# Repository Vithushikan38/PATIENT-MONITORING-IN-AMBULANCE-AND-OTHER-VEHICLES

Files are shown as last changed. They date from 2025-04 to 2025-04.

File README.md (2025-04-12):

# VITAL_SYNC  - Patient monitoring in ambulances and other vehicles



Team

- 2021/E/074    K. Vashiharan -https://www.linkedin.com/in/vashiharan02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      
- 2021/E/164    T. Sarujan    -https://www.linkedin.com/in/sarujan-thirunavukkarasu-2b72bb2b5lipi=urn%3Ali%3Apage%3Ad_flagship3_profile_view_base_contact_details%3Bo2gnX580QsemtR7ihnrzcw%3D%3D
- 2021/E/169    V. Vithushikan-https://www.linkedin.com/in/vvithushikan21
- 2021/E/189    R. Nidhushan  -https://www.linkedin.com/in/nidhushan-rajendran-a22a16244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

Introduction

In emergency situations, timely medical intervention is crucial to saving lives. However, during patient transportation, whether in ambulances or other vehicles, continuous health monitoring remains a significant challenge. Delays in detecting critical conditions can worsen health outcomes, and the lack of real-time communication between vehicles and hospitals further complicates emergency response efforts. Our project aims to develop an advanced patient monitoring system that ensures real-time tracking of vital signs during transportation, enhancing pre-hospital care and improving patient outcomes.

System Architecture


Circuit Design



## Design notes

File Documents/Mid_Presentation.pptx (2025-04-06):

## Project Title: Patient Monitoring in Ambulance and Other Vehicles Course: EC6020: Embedded Systems Design Group No: 31

Team Members:
- 2021/E/074 K. Vashiharan
- 2021/E/164 T. Sarujan
- 2021/E/169 V. Vithushikan
- 2021/E/189 R. Nidhushan

## Introduction

This project addresses the challenge of continuous health monitoring during patient transportation.
The lack of real-time communication with hospitals can worsen patient outcomes.
To improve emergency response, the proposed system enables real-time tracking of vital signs and location, ensuring timely medical intervention and better patient care.

## Problem Statement

Key Challenges:
➢ Delayed response due to lack of real-time data sharing, delaying hospital preparation.
➢ Manual reporting by paramedics can introduce errors
➢ Existing systems are mostly restricted to ambulances.

## Proposed Solution

- Real-time health monitoring (Heart rate, SpO₂, temperature, GPS tracking).
- Cloud-based data transmission for seamless hospital access.
- Instant alerts for critical conditions.
- Multi-vehicle compatibility (ambulances, police, rescue teams,personal vehicles).
- User-friendly dashboard for hospital and paramedics.

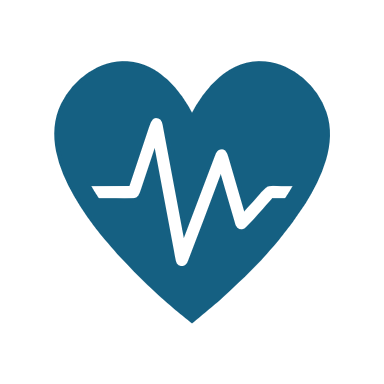
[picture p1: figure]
Heart with Pulse

## Novelty of the Project

- Multi-Vehicle Integration – Not limited to ambulances.
- Predictive Analytics – Alerts before deterioration.
- Low-Cost IoT Implementation – ESP32 + cloud services.
- Real-Time Communication – Mobile & web apps.
- Scalability – Expandable for multiple hospitals/vehicles.

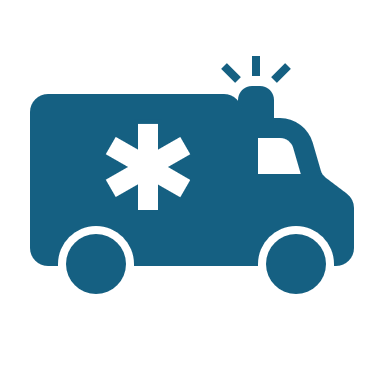
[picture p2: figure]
Ambulance

## High-Level Architecture

- ESP32 – Main controller.
- MAX30100 – Heart rate & SpO₂ sensor.
- DS18B20 – Temperature sensor.
- NEO-6M GPS – Location tracking.
- OLED Display – Onboard status monitoring.
- Cloud Integration – Data transmission.
- Mobile & Web Apps – Real-time patient data visualization.

## Circuit Design

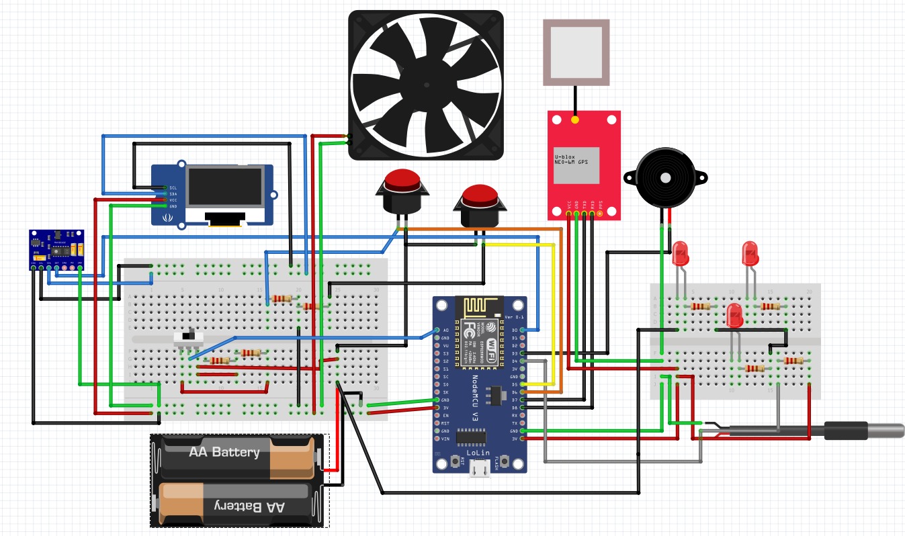
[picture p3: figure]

## WebApp

https://nidhushan13nds.github.io/PATIENT-MONITORING-IN-AMBULANCE-AND-OTHER-VEHICLES/

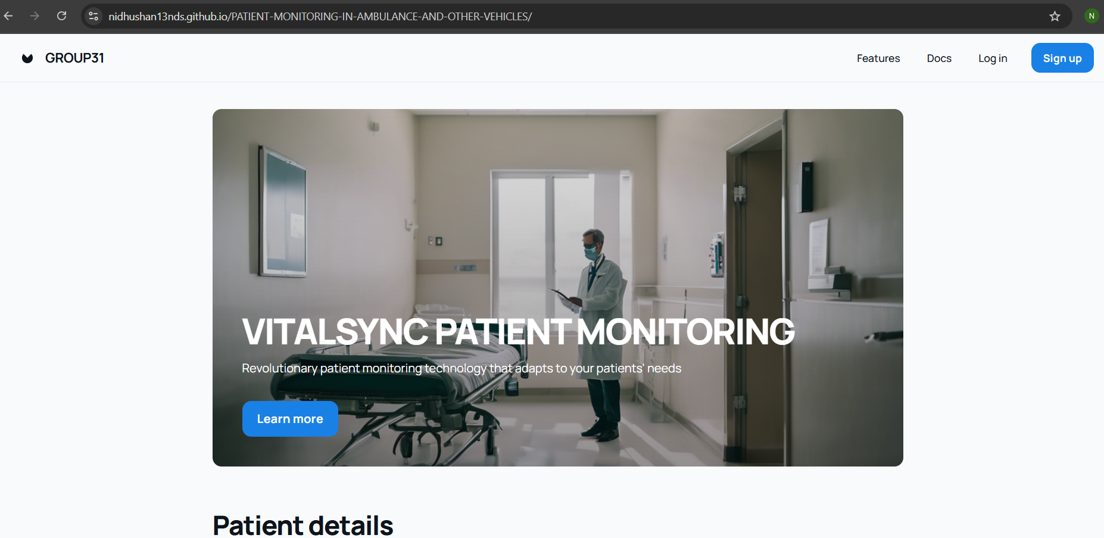
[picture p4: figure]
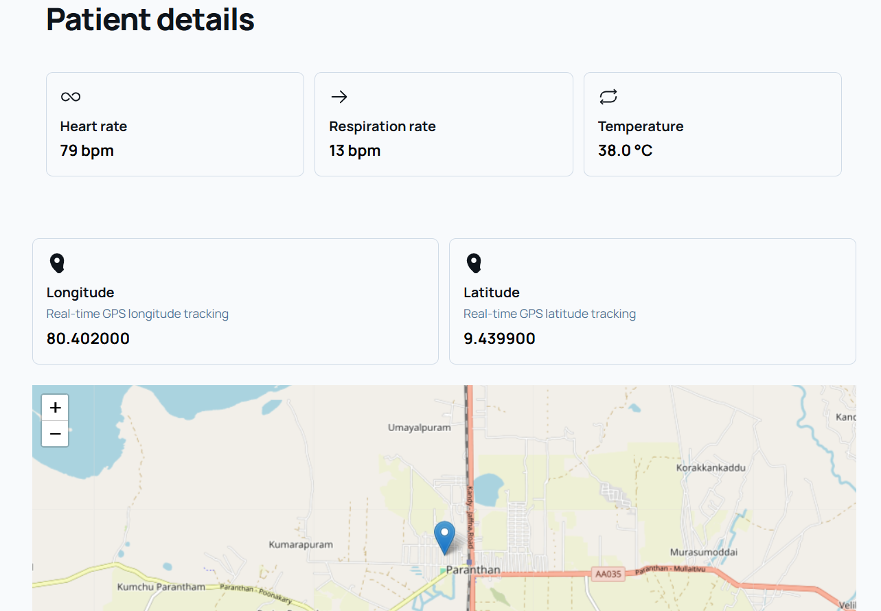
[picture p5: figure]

## Timeline

Activity | Weeks
| 5 | 6 | 7 | 8 | 9 | 10 | 11 | 12 | 13 | 14
Find and purchase components
Design the system and do initial testing
Assemble the hardware and write the firmware
Integrate the sensors and display
Build the web application and set up the database
Test the system and improve the user interface
Fix any issues and do final integration
Write the documentation and prepare for the presentation
Final review and project submission

## Budget

components | price
ESP32 | 1300
DS18B20 temperature sensor | 300
MAX30100 heart rate sensor | 500
NEO6MV2 gps module | 1500
OLED mini display 0.96 inch | 950
Copper board (5cm*7cm) | 150
Jumper wires(40pcs) | 300
Push button, Switch | 80
Outer cover & Other

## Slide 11

Thank you

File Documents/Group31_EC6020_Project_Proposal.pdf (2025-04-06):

GROUP NO - 31

MEMBERS

2021/E/074 K. Vashiharan

2021/E/164 T.Sarujan

2021/E/169 V.Vithushikan

2021/E/189 R.Nidhushan

## PROJECT PROPOSAL

## PATIENT MONITORING IN AMBULANCE AND OTHER VEHICLES

## EC6020:EMBEDDED SYSTEMS DESIGN

## Introduction

In emergency situations, timely medical intervention is crucial to saving lives. However, during patient transportation, whether in ambulances or other vehicles, continuous health monitoring remains a significant challenge. Delays in detecting critical conditions can worsen health outcomes, and the lack of real-time communication between vehicles and hospitals further complicates emergency response efforts. Our project aims to develop an advanced patient monitoring system that ensures real-time tracking of vital signs during transportation, enhancing pre-hospital care and improving patient outcomes.

## Problem Statement

Currently, there is no comprehensive system to monitor patients' real-time health parameters while they are being transported to hospitals. Some critical challenges include:

- Delayed Medical Response: Lack of real-time data sharing leads to delays in preparing hospital facilities for incoming patients.
- Inconsistent Data Transmission: Manual reporting by paramedics can introduce errors and delays.
- Limited Vehicle Integration: Existing systems are mostly restricted to ambulances, leaving other emergency vehicles without adequate monitoring solutions.
- Lack of Predictive Analytics: Current solutions lack the ability to predict potential health deteriorations during transport.

These issues lead to suboptimal emergency care, increased hospital burden, and in some cases, loss of life due to delayed treatment.

## Proposed Solution

To address these challenges, our system will provide a real-time, cloud-based patient monitoring solution that can be deployed in ambulances and other emergency vehicles. Key features include:

1. Real-time Health Monitoring:
- Sensors to continuously measure vital signs such as heart rate, oxygen saturation, temperature, and GPS location.
- Integration with wearable devices for seamless patient data acquisition.
2. Cloud-Based Data Transmission:
- Secure transmission of patient health data to hospital systems via cloud infrastructure.
- Mobile and web applications for paramedics and hospital staff to track patient status.
3. Alerts:
- Instant alerts to medical staff in case of abnormalities.
4. Multi-Vehicle Compatibility:
- Designed for ambulances, police vehicles, rescue teams, and other emergency transport modes.
5. User-Friendly Interface:
- Interactive dashboards for monitoring via mobile and desktop applications.
- Two-way communication between paramedics and hospital teams.

## Novelty of the Project

Our proposed system offers several

novel features that differentiate it from existing solutions:

- Multi-Vehicle Integration: Unlike conventional ambulance-only solutions, our system supports deployment in various emergency vehicles, broadening its application.
- provide proactive alerts, improving patient safety during transport.
- Low-Cost IoT Solution: Utilizing affordable microcontrollers and cloud services to ensure cost-effective implementation.
- Seamless Communication: Integrated mobile and desktop applications will enable real-time interaction between hospital and transport teams.
- Scalability and Flexibility: The system can be scaled to accommodate multiple vehicles and hospital networks, ensuring adaptability across healthcare infrastructures.

## HIGH-LEVEL ARCHITECTURE

1. ESP32 Development Board
- The dual-core processor on the ESP32, together with Wi-Fi and Bluetooth, can comfortably support a load of several sensors that can send updates in real time to cloud platforms.
Low power consumption, and thus ideal for mobile use in ambulances.
Robust SDKs and libraries for integrating different types of communication protocols and peripherals.
- It will serve as the main controller to process and forward the sensor data to cloud servers for real-time access.
2. MAX30102 Pulse Oximeter and Heart Rate Sensor
- Accurate heart rate and SpO₂ measurement, essential for patients suffering from respiratory or cardiac disorders.

Compact size, low power consumption; hence, suitable for portable devices.

- Keeps monitoring the vital signs and transmits the data to ESP32 for further processing and radio transmission.
3. DS18B20 Digital Temperature Sensor
- A high-accuracy, easy-to-use digital temperature sensor.

Suitable for applications that need consistent monitoring of temperature.

- Measures the body temperature of the patient and feeds it to the system in real time.

4. NEO-6M GPS Module
- Reliable GPS module for accurate tracking of the ambulance.

Compact size, and compatible with ESP32.

- Tracks the location of the ambulance to estimate the time of arrival by the hospital staff and to prepare accordingly.
5. OLED Display
- Provides real-time feedback to the ambulance staff regarding the health status of the patient and functionality of the device, Lightweight and energy efficiency.
- Displays vital parameters such as heart rate, oxygen saturation, temperature, and connection status directly in the ambulance.
8. Mobile and Web Applications: Flutter Framework
- Cross-platform development assures consistent user experience across mobile and desktop devices. Intuitive UI for real-time monitoring by hospital staff.
- Displays the patient's health data and ambulance location to hospital staff for better preparation.
9. Power Supply and Battery Backup Reason for Selection: Ensures that the system operates without interruption, even when there is power fluctuation inside the ambulance. Role: Supplies constant power to sensors, ESP32, and display unit

CIRCUIT DESIGN

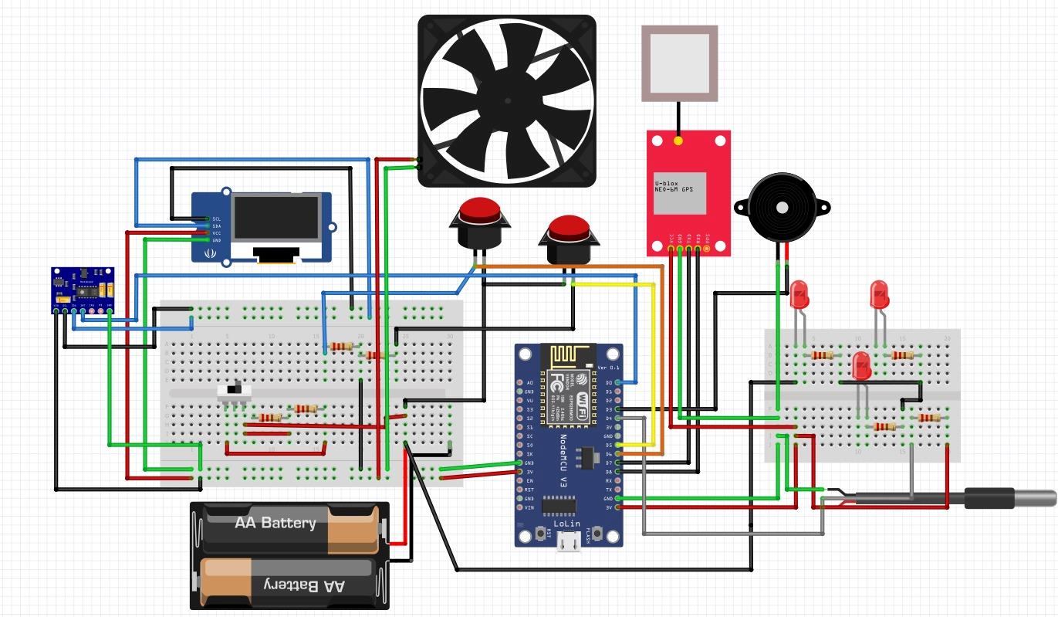
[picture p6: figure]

## Communication Protocols

MQTT (Message Queuing Telemetry Transport)

MQTT is a lightweight, publish-subscribe messaging protocol ideal for IoT-based systems that require low bandwidth and high reliability.

HTTP/HTTPS (HyperText Transfer Protocol / Secure)

HTTP/HTTPS is used for secure communication between the web-based hospital dashboard and the cloud database to retrieve and display patient data.

Bluetooth Low Energy (BLE)

BLE is used for short-range wireless communication between wearable health monitoring devices and the onboard monitoring system in the vehicle.

Github repo link. With updated ReadMe file.

https://github.com/Nidhushan13NDS/PATIENT-MONITORING-IN-AMBULANCE-AND-OTHER-VEHICLES

TimeLine

Budget

Activity | Weeks
5 | 6 | 7 | 8 | 9 | 10 | 11 | 12 | 13 | 14
Find and purchase components
Design the system and do initial testing
Assemble the hardware and write the firmware Integrate the sensors and display
Build the web application and set up the database Test the system and improve the user interface
Fix any issues and do final integration
Write the documentation and prepare for the presentation

Final review and project submission

components | price
ESP32 | 1300
DS18B20 temperature sensor | 300
MAX30100 heart rate sensor | 500
NEO6MV2 gps module | 1500
OLED mini display 0.96 inch | 950
Copper board (5cm*7cm) | 150
Jumper wires(40pcs) | 300
Push button, Switch | 80
CPU fan | 1500
Outer cover & Other | 4000
Total | 10580

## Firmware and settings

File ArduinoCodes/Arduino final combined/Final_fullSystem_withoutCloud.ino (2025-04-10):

#include <Wire.h>
#include <Adafruit_GFX.h>
#include <Adafruit_SSD1306.h>
#include <OneWire.h>
#include <DallasTemperature.h>
#include "MAX30105.h"
#include "spo2_algorithm.h"
#include <TinyGPS++.h>

// OLED Display Settings
#define SCREEN_WIDTH 128
#define SCREEN_HEIGHT 64
Adafruit_SSD1306 display(SCREEN_WIDTH, SCREEN_HEIGHT, &Wire, -1);

// DS18B20 Temperature Sensor
#define ONE_WIRE_BUS 4
OneWire oneWire(ONE_WIRE_BUS);
DallasTemperature sensors(&oneWire);

// MAX30102 Pulse Oximeter
MAX30105 particleSensor;

// Variables for storing SpO2 and heart rate readings
uint32_t irBuffer[100]; // infrared LED sensor data
uint32_t redBuffer[100]; // red LED sensor data
int32_t bufferLength = 100; // data length
int32_t spo2; // SPO2 value
int8_t validSPO2; // indicator to show if the SPO2 calculation is valid
int32_t heartRate; // heart rate value
int8_t validHeartRate; // indicator to show if the heart rate calculation is valid

// GPS Settings
#define RXPin 16
#define TXPin 17
#define GPSBaud 9600
HardwareSerial gpsSerial(2);
TinyGPSPlus gps;

// GPIO Pins
#define BUTTON_PIN 14
#define BUZZER_PIN 27
#define LED_PIN 26
#define LED_PINA 32
#define LED_PINB 18

// Show message on OLED
void showMessage(const char* message, int size, int x, int y, int delayTime) {
    display.clearDisplay();
    display.setTextSize(size);
    display.setCursor(x, y);
    display.setTextColor(WHITE);
    display.println(message);
    display.display();
    delay(delayTime);
}

// Display patient report
void showPatientReport(float tempC, int32_t bpm, int32_t spo2) {
    display.clearDisplay();
    display.setTextSize(1);
    display.setCursor(10, 5);
    display.println("Patient Report:");

    display.setCursor(10, 20);
    display.print("Temp: ");
    display.print(tempC, 1);
    display.write(248);  // Degree symbol
    display.println("C");

    display.setCursor(10, 35);
    display.print("HR: ");
    display.print(bpm);
    display.println(" BPM");

    display.setCursor(10, 50);
    display.print("SpO2: ");
    display.print(spo2);
    display.println(" %");

    display.display();
    delay(1000);
}

// Display GPS info
void showGPSData() {
    display.clearDisplay();
    display.setTextSize(1);
    display.setCursor(10, 5);
    display.println("GPS Details:");

    if (gps.location.isValid()) {
        display.setCursor(10, 20);
        display.print("Lat: ");
        display.println(gps.location.lat(), 6);

        display.setCursor(10, 30);
        display.print("Lon: ");
        display.println(gps.location.lng(), 6);
    } else {
        display.setCursor(10, 20);
        display.println("GPS: No Fix");
    }

    display.setCursor(10, 40);
    display.print("Date: ");
    if (gps.date.isValid()) {
        display.print(gps.date.day());
        display.print("/");
        display.print(gps.date.month());
        display.print("/");
        display.println(gps.date.year());
    } else {
        display.println("N/A");
    }

    display.setCursor(10, 50);
    display.print("Time: ");
    if (gps.time.isValid()) {
        int hour = gps.time.hour() + 5;
        int minute = gps.time.minute() + 30;
        if (minute >= 60) { minute -= 60; hour++; }
        if (hour >= 24) { hour -= 24; }

        if (hour < 10) display.print("0");
        display.print(hour); display.print(":");
        if (minute < 10) display.print("0");
        display.print(minute); display.print(":");
        if (gps.time.second() < 10) display.print("0");
        display.println(gps.time.second());
    } else {
        display.println("N/A");
    }

    display.display();
    delay(1000);
}

void setup() {
    Serial.begin(115200);
    Serial.println("Booting...");

    Wire.begin();
    gpsSerial.begin(GPSBaud, SERIAL_8N1, RXPin, TXPin);

    // OLED init
    Serial.println("Initializing OLED...");
    if (!display.begin(SSD1306_SWITCHCAPVCC, 0x3C)) {
        Serial.println("SSD1306 allocation failed");
        while (1);
    }
    display.clearDisplay();
    display.display();
    delay(1000);

    // Temperature sensor init
    sensors.begin();
    Serial.println("DS18B20 initialized");

    // MAX30102 init
    Serial.println("Initializing MAX30102...");
    if (!particleSensor.begin(Wire, I2C_SPEED_FAST)) {
        Serial.println("MAX30102 was not found. Please check wiring/power.");
        while (1);
    }
    
    // Configure MAX30102 sensor settings
    byte ledBrightness = 60; // Options: 0=Off to 255=Max
    byte sampleAverage = 4; // Options: 1, 2, 4, 8, 16, 32
    byte ledMode = 2; // Options: 1=Red only, 2=Red+IR, 3=Red+IR+Green
    int sampleRate = 100; // Options: 50, 100, 200, 400, 800, 1000, 1600, 3200
    int pulseWidth = 411; // Options: 69, 118, 215, 411
    int adcRange = 4096; // Options: 2048, 4096, 8192, 16384

    particleSensor.setup(ledBrightness, sampleAverage, ledMode, sampleRate, pulseWidth, adcRange);
    Serial.println("MAX30102 initialized");

    // GPIO setup
    pinMode(BUTTON_PIN, INPUT_PULLUP);  // button pressed = LOW
    pinMode(BUZZER_PIN, OUTPUT);
    pinMode(LED_PIN, OUTPUT);
    pinMode(LED_PINA, OUTPUT);
    pinMode(LED_PINB, OUTPUT);
    digitalWrite(BUZZER_PIN, LOW);
    digitalWrite(LED_PIN, LOW);
    digitalWrite(LED_PINA, LOW); // Initially OFF
    digitalWrite(LED_PINB, LOW); // Initially OFF

    // LED behavior
    digitalWrite(LED_PINA, HIGH);  // Pin 18 LED on initially
    delay(1000);                    // Wait for 1 second
    digitalWrite(LED_PINA, LOW);    // Pin 18 LED off after 1 second

    digitalWrite(LED_PINB, HIGH);  // Pin 32 LED on for the rest of the system runtime

    // Show initial messages
    showMessage("WELCOME", 2, 20, 25, 2000);
    showMessage("VitalSync\n  Hospital", 2, 10, 25, 2000);
    showMessage("New\n  Patient!", 2, 45, 20, 2000);
}

void loop() {
    // Read temperature sensor
    sensors.requestTemperatures();
    float tempC = sensors.getTempCByIndex(0);
    
    // Read MAX30102 sensor
    bufferLength = 100;
    
    // Read samples for calculating SpO2 and heart rate
    for (byte i = 0; i < bufferLength; i++) {
        while (particleSensor.available() == false) {
            particleSensor.check(); // Check if new data is available
            delay(10);
        }
        
        redBuffer[i] = particleSensor.getRed();
        irBuffer[i] = particleSensor.getIR();
        particleSensor.nextSample(); // Move to next sample
    }

    // Calculate heart rate and SpO2
    maxim_heart_rate_and_oxygen_saturation(irBuffer, bufferLength, redBuffer, &spo2, &validSPO2, &heartRate, &validHeartRate);
    
    // If readings are valid, show patient report
    if (validSPO2 && validHeartRate) {
        showPatientReport(tempC, heartRate, spo2);
        delay(3000);
    } else {
        // If readings are invalid, show message
        showMessage("Calculating\nVitals...", 1, 20, 20, 1000);
    }

    // Process GPS data
    while (gpsSerial.available() > 0) {
        gps.encode(gpsSerial.read());
    }
    showGPSData();
    delay(500);

    // Check for button press (LOW = pressed with pull-up)
    if (digitalRead(BUTTON_PIN) == LOW) {
        delay(50);
          // debounce
        if (digitalRead(BUTTON_PIN) == LOW) {
            // Blink and beep 3 times (button press required)
            for (int i = 0; i < 3; i++) {
                digitalWrite(LED_PIN, HIGH);
                digitalWrite(BUZZER_PIN, HIGH);
                delay(200);
                digitalWrite(LED_PIN, LOW);
                digitalWrite(BUZZER_PIN, LOW);
                delay(200);
            }

            // Show "Thank You" message
            showMessage("Thank You!", 2, 5, 25, 3000);
            
            // Restart system
            ESP.restart();
        }
    }
}

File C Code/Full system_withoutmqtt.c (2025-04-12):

// main.c for ESP-IDF framework
#include <stdio.h>
#include <string.h>
#include <stdlib.h>
#include "freertos/FreeRTOS.h"
#include "freertos/task.h"
#include "driver/gpio.h"
#include "driver/i2c.h"
#include "driver/uart.h"
#include "esp_log.h"
#include "esp_system.h"
#include "sdkconfig.h"

static const char *TAG = "VitalSync";

// GPIO Pin Definitions
#define BUTTON_PIN          13
#define BUZZER_PIN          25
#define LED_PIN             26
#define LED_PINA            32
#define LED_PINB            18
#define ONE_WIRE_BUS        4

// I2C Configuration
#define I2C_MASTER_SCL      22    // SCL pin
#define I2C_MASTER_SDA      21    // SDA pin
#define I2C_MASTER_PORT     I2C_NUM_0
#define I2C_MASTER_FREQ_HZ  400000

// UART Configuration for GPS
#define GPS_UART_NUM        UART_NUM_2
#define GPS_UART_RX_PIN     16
#define GPS_UART_TX_PIN     17
#define GPS_UART_BAUD_RATE  9600
#define GPS_UART_BUF_SIZE   1024

// OLED Display Configuration
#define SCREEN_WIDTH        128
#define SCREEN_HEIGHT       64
#define OLED_ADDR           0x3C

// SSD1306 Commands
#define SSD1306_ADDR                    0x3C
#define SSD1306_CMD_DISPLAY_OFF         0xAE
#define SSD1306_CMD_DISPLAY_ON          0xAF
#define SSD1306_CMD_SET_CONTRAST        0x81
#define SSD1306_CMD_DISPLAY_ALL_ON_RESUME 0xA4
#define SSD1306_CMD_DISPLAY_ALL_ON      0xA5
#define SSD1306_CMD_NORMAL_DISPLAY      0xA6
#define SSD1306_CMD_INVERT_DISPLAY      0xA7
#define SSD1306_CMD_SET_MULTIPLEX       0xA8
#define SSD1306_CMD_SET_DISPLAY_OFFSET  0xD3
#define SSD1306_CMD_SET_START_LINE      0x40
#define SSD1306_CMD_SET_SEGMENT_REMAP   0xA0
#define SSD1306_CMD_SET_COM_SCAN_DIR    0xC0
#define SSD1306_CMD_SET_COM_PINS        0xDA
#define SSD1306_CMD_SET_MEMORY_ADDR_MODE 0x20
#define SSD1306_CMD_SET_COLUMN_ADDR     0x21
#define SSD1306_CMD_SET_PAGE_ADDR       0x22
#define SSD1306_CMD_CHARGE_PUMP         0x8D

// MAX30102 registers
#define MAX30105_ADDRESS           0x57
#define MAX30105_REG_INTR_STATUS_1 0x00
#define MAX30105_REG_INTR_STATUS_2 0x01
#define MAX30105_REG_INTR_ENABLE_1 0x02
#define MAX30105_REG_INTR_ENABLE_2 0x03
#define MAX30105_REG_FIFO_WR_PTR   0x04
#define MAX30105_REG_FIFO_OVF      0x05
#define MAX30105_REG_FIFO_RD_PTR   0x06
#define MAX30105_REG_FIFO_DATA     0x07
#define MAX30105_REG_MODE_CONFIG   0x09
#define MAX30105_REG_SPO2_CONFIG   0x0A
#define MAX30105_REG_LED1_PA       0x0C
#define MAX30105_REG_LED2_PA       0x0D
#define MAX30105_REG_LED3_PA       0x0E
#define MAX30105_REG_MULTI_LED     0x11
#define MAX30105_REG_TEMP_INTR     0x1F
#define MAX30105_REG_TEMP_DATA     0x20
#define MAX30105_REG_REV_ID        0xFE
#define MAX30105_REG_PART_ID       0xFF

// Variables for storing SpO2 and heart rate readings
uint32_t irBuffer[100];  // infrared LED sensor data
uint32_t redBuffer[100]; // red LED sensor data
int32_t bufferLength = 100; // data length
int32_t spo2 = 0; // SPO2 value
int8_t validSPO2 = 0; // indicator to show if the SPO2 calculation is valid
int32_t heartRate = 0; // heart rate value
int8_t validHeartRate = 0; // indicator to show if the heart rate calculation is valid

// GPS data structure
typedef struct {
    double latitude;
    double longitude;
    uint8_t day;
    uint8_t month;
    uint16_t year;
    uint8_t hour;
    uint8_t minute;
    uint8_t second;
    bool location_valid;
    bool time_valid;
    bool date_valid;
} gps_data_t;

gps_data_t gps_data = {0};

// Function prototypes
static esp_err_t i2c_master_init(void);
static esp_err_t ssd1306_init(void);
static esp_err_t ssd1306_clear(void);
static esp_err_t ssd1306_display_text(const char *text, int x, int y, int size);
static esp_err_t max30105_init(void);
static esp_err_t max30105_read_sensor(void);
static float ds18b20_read_temp(void);
static void parse_gps_data(const char* buffer, size_t len);
static void show_message(const char* message, int size, int x, int y, int delay_time);
static void show_patient_report(float temp_c, int32_t bpm, int32_t spo2_value);
static void show_gps_data(void);

// I2C master initialization
static esp_err_t i2c_master_init(void) {
    i2c_config_t conf = {
        .mode = I2C_MODE_MASTER,
        .sda_io_num = I2C_MASTER_SDA,
        .scl_io_num = I2C_MASTER_SCL,
        .sda_pullup_en = GPIO_PULLUP_ENABLE,
        .scl_pullup_en = GPIO_PULLUP_ENABLE,
        .master.clk_speed = I2C_MASTER_FREQ_HZ,
    };
    
    esp_err_t ret = i2c_param_config(I2C_MASTER_PORT, &conf);
    if (ret != ESP_OK) {
        return ret;
    }
    
    return i2c_driver_install(I2C_MASTER_PORT, conf.mode, 0, 0, 0);
}

// Write to I2C device
static esp_err_t i2c_write_byte(uint8_t device_addr, uint8_t reg_addr, uint8_t data) {
    i2c_cmd_handle_t cmd = i2c_cmd_link_create();
    i2c_master_start(cmd);
    i2c_master_write_byte(cmd, (device_addr << 1) | I2C_MASTER_WRITE, true);
    i2c_master_write_byte(cmd, reg_addr, true);
    i2c_master_write_byte(cmd, data, true);
    i2c_master_stop(cmd);
    esp_err_t ret = i2c_master_cmd_begin(I2C_MASTER_PORT, cmd, 1000 / portTICK_PERIOD_MS);
    i2c_cmd_link_delete(cmd);
    return ret;
}

// Read from I2C device
static esp_err_t i2c_read_byte(uint8_t device_addr, uint8_t reg_addr, uint8_t *data) {
    i2c_cmd_handle_t cmd = i2c_cmd_link_create();
    i2c_master_start(cmd);
    i2c_master_write_byte(cmd, (device_addr << 1) | I2C_MASTER_WRITE, true);
    i2c_master_write_byte(cmd, reg_addr, true);
    i2c_master_start(cmd);
    i2c_master_write_byte(cmd, (device_addr << 1) | I2C_MASTER_READ, true);
    i2c_master_read_byte(cmd, data, I2C_MASTER_LAST_NACK);
    i2c_master_stop(cmd);
    esp_err_t ret = i2c_master_cmd_begin(I2C_MASTER_PORT, cmd, 1000 / portTICK_PERIOD_MS);
    i2c_cmd_link_delete(cmd);
    return ret;
}

// Initialize SSD1306 OLED display
static esp_err_t ssd1306_init(void) {
    esp_err_t ret;
    
    // Send initialization commands
    uint8_t init_cmds[] = {
        SSD1306_CMD_DISPLAY_OFF,
        SSD1306_CMD_SET_MULTIPLEX, 0x3F,
        SSD1306_CMD_SET_DISPLAY_OFFSET, 0x00,
        SSD1306_CMD_SET_START_LINE | 0x00,
        SSD1306_CMD_SET_SEGMENT_REMAP | 0x01,
        SSD1306_CMD_SET_COM_SCAN_DIR | 0x08,
        SSD1306_CMD_SET_COM_PINS, 0x12,
        SSD1306_CMD_SET_CONTRAST, 0x7F,
        SSD1306_CMD_DISPLAY_ALL_ON_RESUME,
        SSD1306_CMD_NORMAL_DISPLAY,
        SSD1306_CMD_CHARGE_PUMP, 0x14,
        SSD1306_CMD_DISPLAY_ON
    };
    
    for (int i = 0; i < sizeof(init_cmds); i++) {
        ret = i2c_write_byte(OLED_ADDR, 0x00, init_cmds[i]);
        if (ret != ESP_OK) {
            ESP_LOGE(TAG, "OLED init command %d failed", i);
            return ret;
        }
    }
    
    return ESP_OK;
}
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

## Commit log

2025-03-07 patientino code
2025-03-15 Create ArduinoCodes
2025-03-15 Create Sample_PatientMonitoring
2025-03-28 Add files via upload
    max30100 arduino codes
2025-04-07 NEO6M_c
    Added C Code for NEO6M sensor
2025-04-07 Circuit diagram
    Fritzing software circuit diagram uploaded
    [patient monitoring.fzz]
2025-04-07 NEO6M.c
    the NEO6M sensor file uploades
2025-04-09 Temperature sensor was connected with mqtt
2025-04-09 Heart rate sensor was connected with mqtt
2025-04-09 GPS and Temperature sensors were connected with mqtt and works
2025-04-10 Add files via upload
    updated circuit diagram
    [patient monitoring.fzz]
2025-04-10 updated circuit diagram.
2025-04-10 Arduino final combied code was uploded
2025-04-10 GPS and Temperature were connected with mqtt broker and works correctly
    [GPS.c, Temperature sensor.c]
2025-04-10 Temperature and GPS were connected with mqtt and combined successful in c language
2025-04-10 MAX30102 heart rate sensor c code was updated
